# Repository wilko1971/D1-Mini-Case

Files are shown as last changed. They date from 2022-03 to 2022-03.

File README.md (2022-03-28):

# D1-Mini-Case

I really liked the look of the D1 Mini cases D3nce designed over on thingiverse.  I just found them a little too delicate for my needs.  I had originally planned to just take the original designs and make the walls a little thicker, but things took on a life of their own.

The main system is split into 3 parts, base separator and top, then there are a couple of supporting files for mounting the system.  All files are on Tinker Cad and are public if you want to add more sensors or remix anything.

# Base
I have made the base deep enough to allow the use of Dupont pins and recommend having male pins on the D1, to allow for clearance.  

## Variations
### Wall Fixings
This has slots in the base to allow the system to be mounted flush to a wall.

### DC In
The USB cable slot has been replaced with a hole.  This has been left deliberately small allowing it to be drilled to size.

# Separator
The separator is the heart of the system, allowing the mounting of different sensors, and is supposed to help shield against the heat generated by the D1 mini.  The standard version is simply a blank plate with a hole to pass wires from the sensor to the D1.   To mount sensors, mark the mounting holes, drill, and attach posts.  I’ve found M2 nylon mounting posts work in most situations.
https://www.amazon.co.uk/s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

# Top
I’ve two main versions of the top Standard, and Short.  Short is pretty much what it says and is a shorter version of the standard top.  I prefer the short versions as the system can become long when the standard top is attached.

Update 2022-03-28: I've added a new two part top that snaps together to hide the screws, giving a cleaner look. This came about during my experiments trying to make a neat looking lid that spins for the Rotary Encoder

# Stands
Both stands simply allow the system to be viewed on its side and have been made to support LCD screens.

## Desk Stand
You should be able to feed a USB cable through the back and sit the system on top of the base.  I’ve had varying degrees of success depending on the cable used, I tend to find the cables bought from the dollar / pound shop work best.  I have taken to adding a small piece of blu tack to keep everything in place.

## Wall Stand
This consists of 2 parts the base is attached to a surface and the clasp holds the D1 Mini.  The tolerances are pretty tight so you shouldn’t need any bolts but if you do the clasp can be secured with 2 M2 bolts.

# Sensor Variants.

## HC SR04 – Ultrasonic Distance Sensor
https://www.amazon.co.uk/s?k=HC+SR04&crid=U6Z7LBEP6SK6&sprefix=hc+sr04%2Caps%2C86&ref=nb_sb_noss

This has both a separator and top.

## 12864 128x64 OLED
https://www.amazon.co.uk/gp/product/B08FD643VZ/ref=ppx_yo_dt_b_search_asin_title?ie=UTF8&psc=1

This has both a separator and top.

## HC-SR501 PIR
https://www.amazon.co.uk/gp/product/B088LR9KRP/ref=ppx_yo_dt_b_search_asin_title?ie=UTF8&psc=1

This has both a separator and top.

## BMP280 Temperature Sensor
https://www.amazon.co.uk/Pressure-Barometric-Altitude-Atmospheric-Precision/dp/B08219H195

This has just a separator, and top should work

## SH1106 128x64 OLED
https://www.amazon.co.uk/gp/product/B07FYG8MZN/ref=ppx_yo_dt_b_search_asin_title?ie=UTF8&psc=1

This has both a separator and top.

## SIM800L
https://www.amazon.co.uk/gp/product/B07RKVL1DW/ref=ppx_yo_dt_b_search_asin_title?ie=UTF8&psc=1

This has a separator and top and setting it up is quite awkward.  The SIM800L requires a 2amp power source.  As the D1 mini can’t provide this much power through its pins, you will need to use the DC input base, and split the power to both the D1 Mini and the SIM800L.  Attaching the antenna is the most awkward part of the process.  You will need to tuck most of the antenna wire under the SIM800L and carefully line up the top so the notch with the antenna base.  I also recommend having the antenna attached as you do this, as it will be needed later and gives better purchase.  Once the top is in place, pull on the antenna gently, this should force nut on the back to lock against the side and you can then tighten the outside bolt.  Once the antenna is in place line up the fixing holes with the base and screw it together.

## Rotary Encoder
https://www.amazon.co.uk/DIFCUL-Degree-Encoder-Development-Arduino/dp/B09P52R8VD

This is another awkward sensor.  When purchased the pins point out and they need to point down to fit in the case. You can unsolder the original header and replace it with a new one, but there's another problem. There are no solder points at the top of the PCB so you need to solder the header in reverse and remove the plastic spacer to make it all fit. Once this is done it's pretty simple to screw everything together.

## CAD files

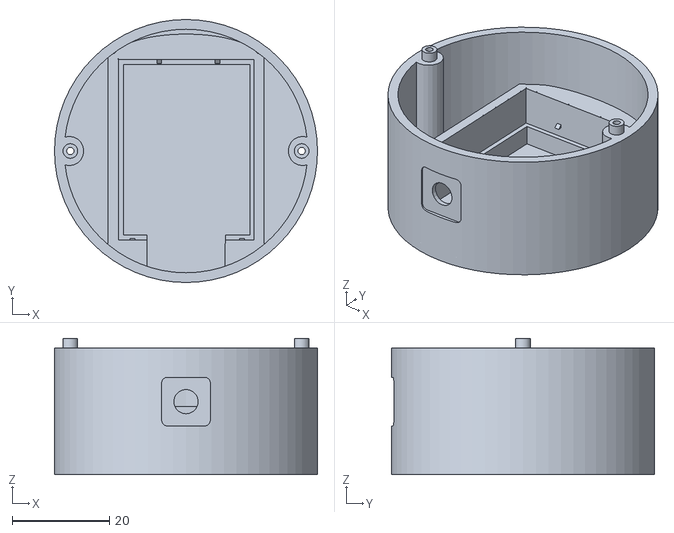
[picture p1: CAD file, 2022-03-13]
Base/D1 Round Remix DC In.stl
54.0 x 54.0 x 28.0

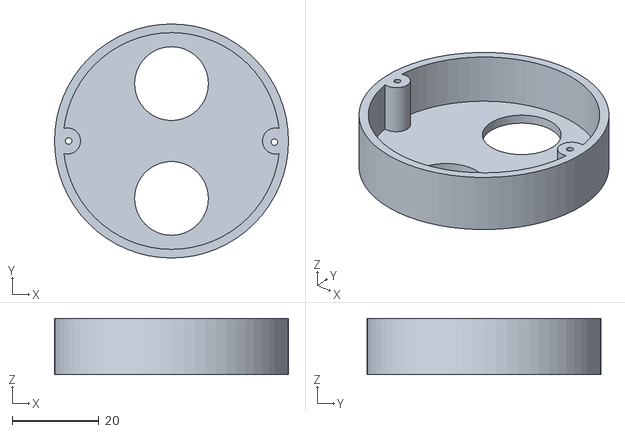
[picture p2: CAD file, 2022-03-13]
Distance SR04/D1 Remix Round Top HC_SR04.stl
54.0 x 54.0 x 13.0

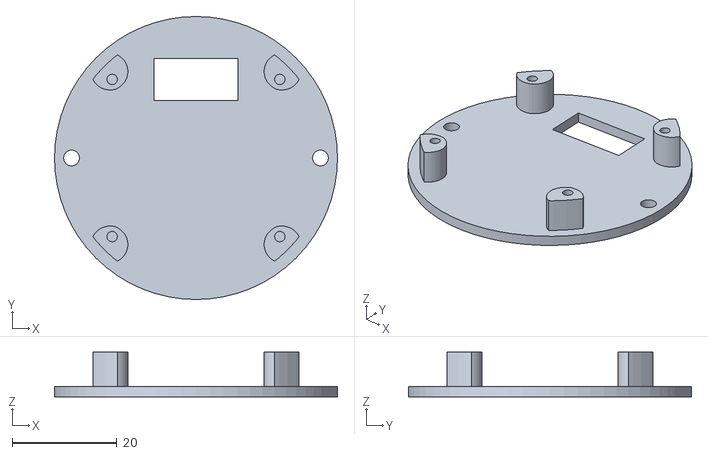
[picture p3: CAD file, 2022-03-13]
OLED 12864 128x64/D1 Round Remix Separator OLED 12864 128x64.stl
54.0 x 54.0 x 8.50

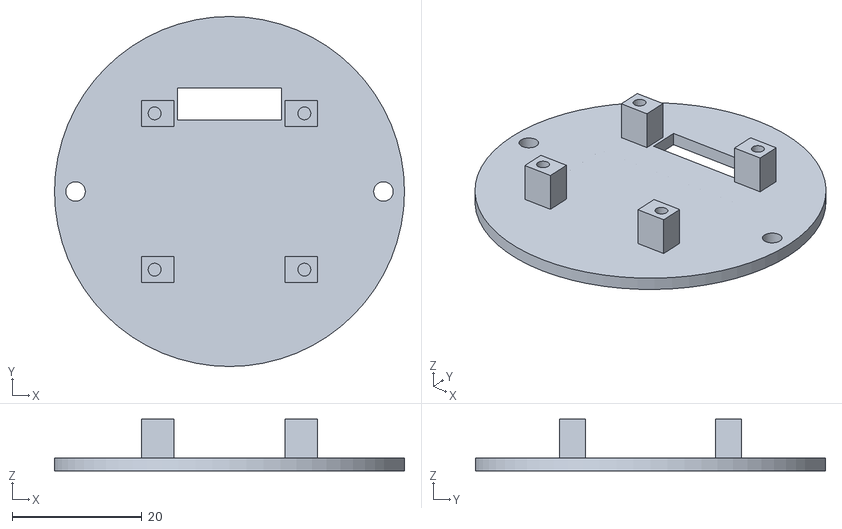
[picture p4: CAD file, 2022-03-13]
OLED SH1106 128x64/D1 Round Remix Separator SH1106 128x64 .stl
54.0 x 54.0 x 8.00

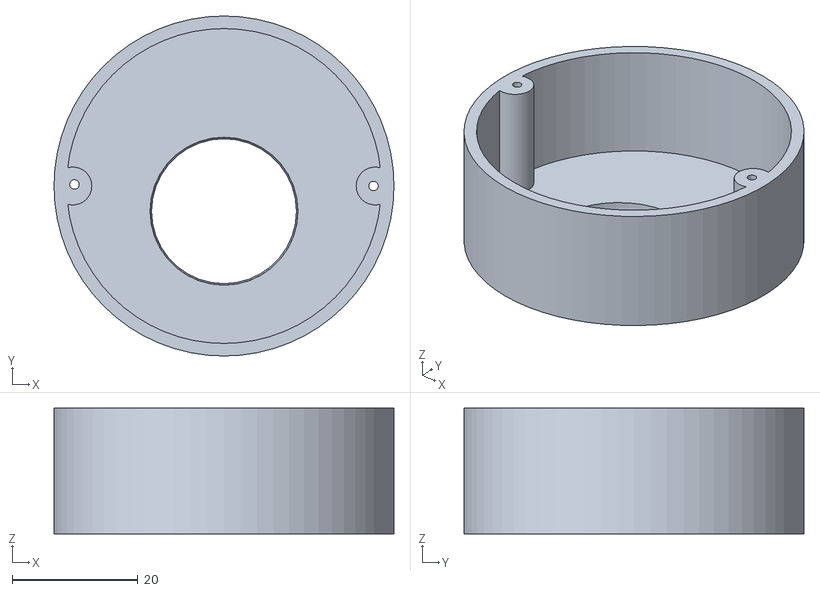
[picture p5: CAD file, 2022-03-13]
PIR HC-SR501/D1 Round Remix Top PIR HC-SR501.stl
54.0 x 54.0 x 20.0

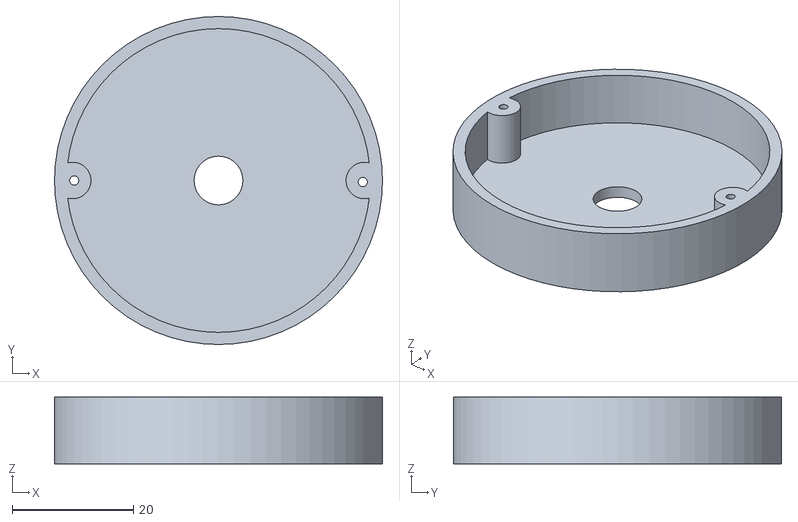
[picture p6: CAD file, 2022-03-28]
Rotary Encoder/D1 Round Remix Top Rotary Encoder.stl
54.0 x 54.0 x 11.0

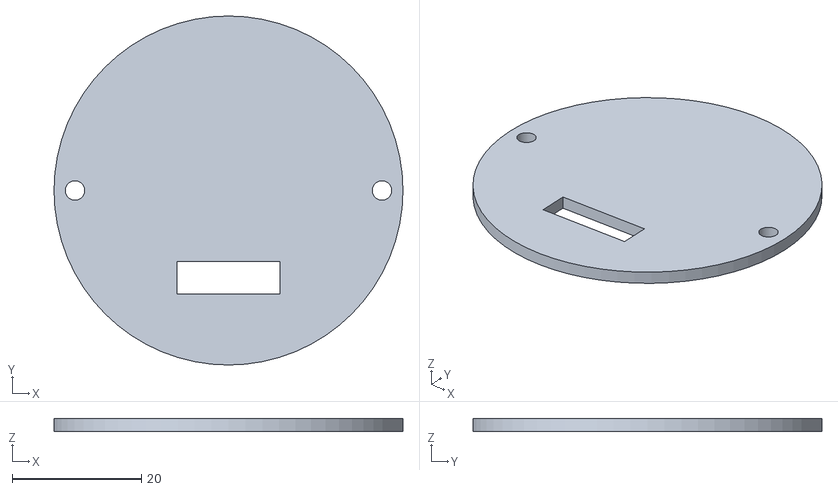
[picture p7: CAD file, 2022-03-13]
Separator/D1 Round Remix Separator.stl
54.0 x 54.0 x 2.00

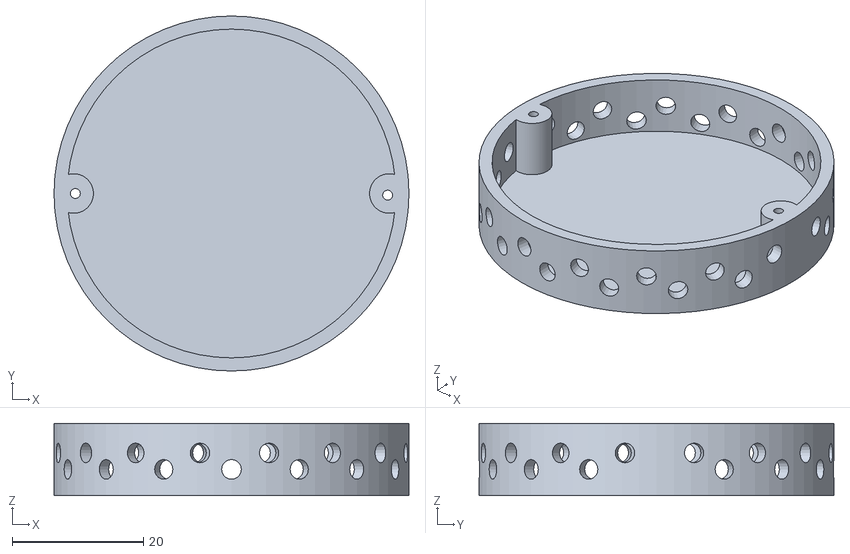
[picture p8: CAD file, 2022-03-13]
Short Tops/D1 Round Remix Short Top Holes.stl
54.0 x 54.0 x 11.0

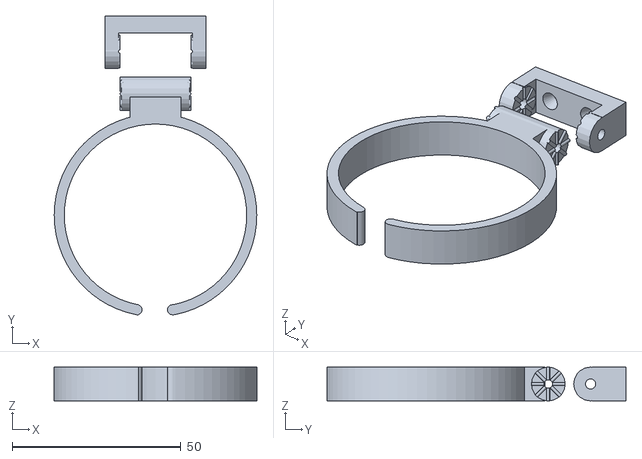
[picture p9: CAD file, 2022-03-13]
Stands/D1 Round Remix Stand.stl
60.0 x 88.6 x 10.0

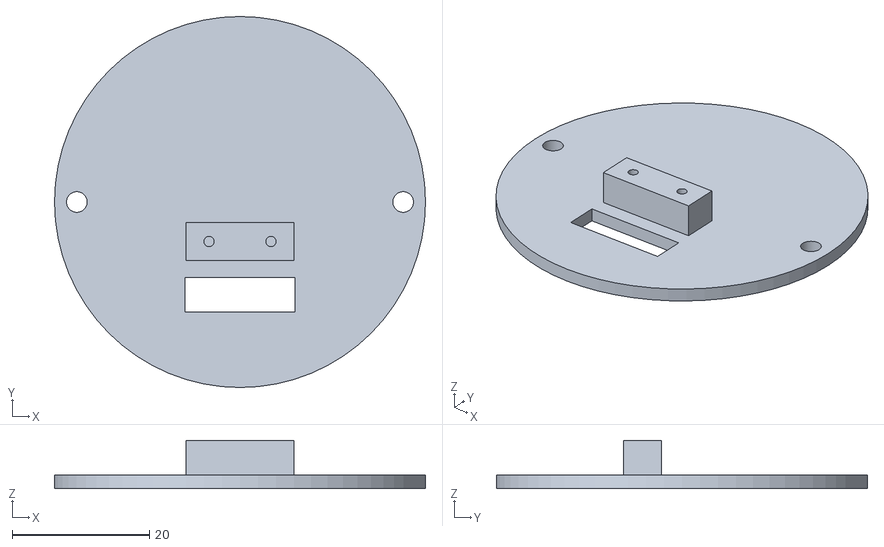
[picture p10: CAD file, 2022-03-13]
Temp BMP280/D1 Round Remix Separator TEMP SENSOR BMP280.stl
54.0 x 54.0 x 7.00

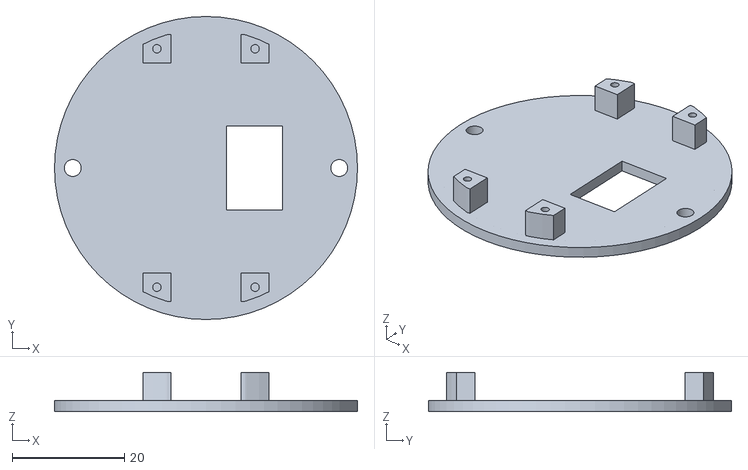
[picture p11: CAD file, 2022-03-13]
Distance SR04/D1 Round Remix Separator HC_SR04.stl
54.0 x 54.0 x 7.00

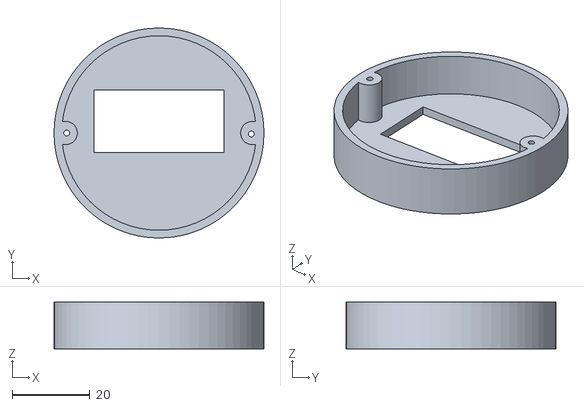
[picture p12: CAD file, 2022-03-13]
OLED 12864 128x64/D1 Round Remix Top OLED 12864 128x64.stl
54.0 x 54.0 x 12.0

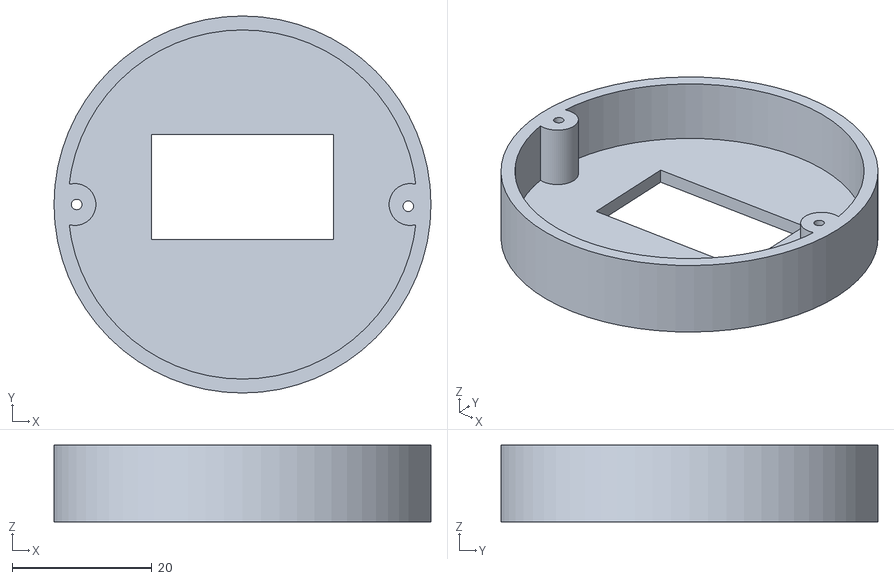
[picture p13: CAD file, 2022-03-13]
OLED SH1106 128x64/D1 Round Remix Top SH1106 128x64 .stl
54.0 x 54.0 x 11.0

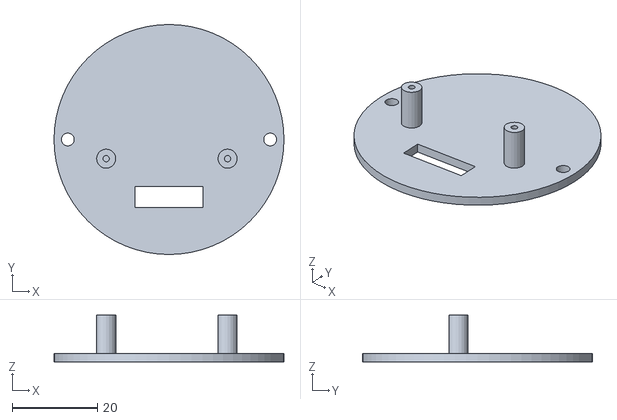
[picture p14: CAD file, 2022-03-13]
PIR HC-SR501/D1 Round Remix Separator PIR HC-SR501.stl
54.0 x 54.0 x 11.0

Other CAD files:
Sim800L/D1 Round Remix Top SIM800L.stl
Base/D1 Round Remix Base.stl
Rotary Encoder/D1 Round Remix Separator Rotary Encoder.stl
Short Tops/D1 Round Remix Short Top.stl
Base/D1 Round Remix Base Wall Fixings.stl
Sim800L/D1 Round Remix Separator SIM800L.stl
Stands/D1 Remix Round Desk Stand.stl
Tops/D1 Round Remix Top Hidden Screws.stl
Tops/D1 Round Remix Top Holes.stl
Tops/D1 Round Remix Top Lines.stl
Tops/D1 Round Remix Top Slats.stl
Tops/D1 Round Remix Top Solid.stl

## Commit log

2022-03-13 Updated top
    Updated top as the notch wasn't wide or deep enough.
    [D1 Round Remix Top SIM800L.stl]
2022-03-28 Hidden Screw Top
    Added a new top that hides the screws used to fit the system together
    [D1 Round Remix Top Hidden Screws.stl]
2022-03-28 Rotary Encoder
    New base and top for Rotary Encoder
    [D1 Round Remix Separator Rotary Encoder.stl, D1 Round Remix Top Rotary Encoder.stl]
